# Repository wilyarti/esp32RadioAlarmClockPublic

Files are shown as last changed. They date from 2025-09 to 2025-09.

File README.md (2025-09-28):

# Thanks to:
- https://oleddisplay.squix.ch/ <- font generation
- https://javl.github.io/image2cpp/
- https://www.svgrepo.com/svg/521874/telegram
- Volos Projects for inspiration

I'll help if you need it. Basically in TFT eSPI library set the config for your screen.

In hardware_definitions.h set you i2s pins.

WiFi configuration and Telegram token setting is done via serial on boot.

STL files are included for the case.

The license is BSD 2 Clause. Have fun.

Looks like this:

Example of device screen.
Example of device screen.

# Features:
1. Preferences.h configuration of almost all functions
2. Stores 5 WiFi APs and tries each on boot
3. Stores 8 Radio Stations
4. Can play any radio station URL
5. Can be configured via Serial or via telegram
6. Alarm configured via serial/telgram includes volume
7. Power limiting available to reduce battery consumption
8. Has horizontal graphs for volume, buffer and power use
9. Records ping ms for current station
10. Clock and alarm clock use rainbow coloring for HH, MM and SS
11. Timezone programmable
12. Keeps time up to date automagically
13. Has battery and wifi signal icons
14. Lots of other stuff I forgot

# Bugs:
For some reason it plays fine when I proxy high bitrate music streams through my personal server, but struggles when directly streaming.
Some other random memory leaks.
This device isnt super powerful so graphic updates are gradual. Like individual letters, numbers etc are deleted and redrawn. 

# Design:
Uses a "fat struct" called g_machine for almost everything it runs. I've put the functions into seperate libraries. The crazy thing is how good the sound quality is....
As for the hardware I basically just threw parts together.

# Parts list:
- TTGO T4 v1.1 (old stock I had)
- 2PCS 2" 4Ohm 3W DIY Small Full Range Audio Speaker
- TPA3110 XH-A232 30W+30W 2.0 Channel Digital Stereo Audio Power Amplifier Board DC 8-26V 3A
- MCU-219 INA219 I2C port Zero drift bidirectional current power supply monitoring sensor module
- TPS61088 5V 9V 12V Adjustable Boost Step Up Board Module Switch Power Supply Module 
- 3.7V 2500mAh battery (salvaged from somewhere)
- Interface I2S PCM5102A DAC Decoder GY-PCM5102 I2S Player




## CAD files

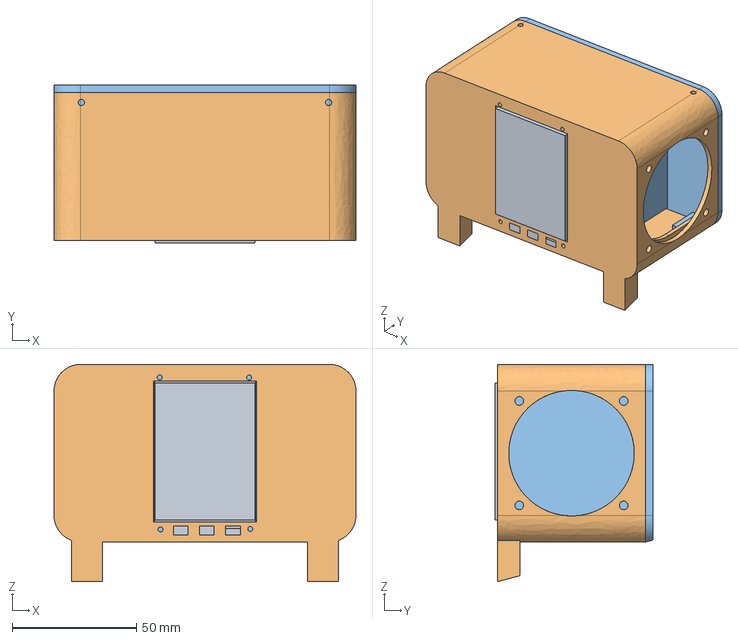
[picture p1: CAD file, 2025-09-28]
3D_models/speaker_box.igs
121.5 x 63.5 x 87.4 mm

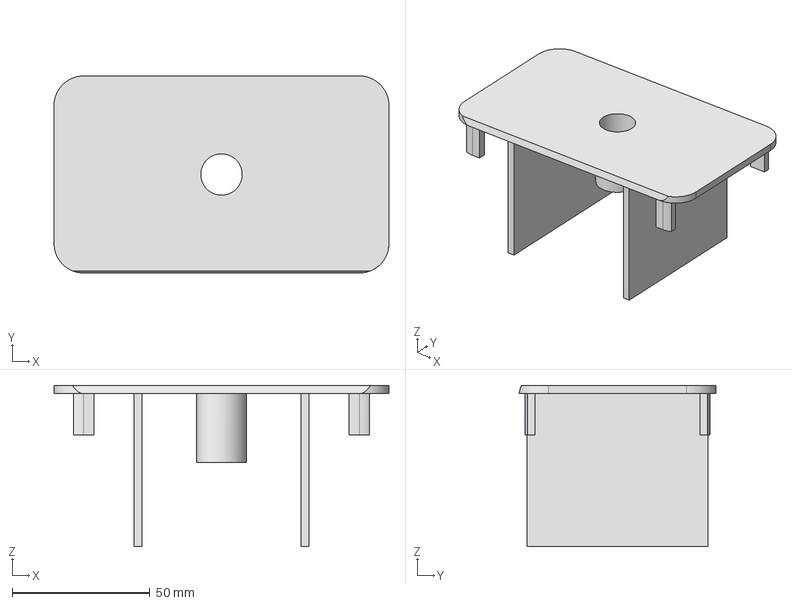
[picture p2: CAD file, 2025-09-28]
3D_models/casing_backing.igs
121.5 x 71.5 x 58.5 mm

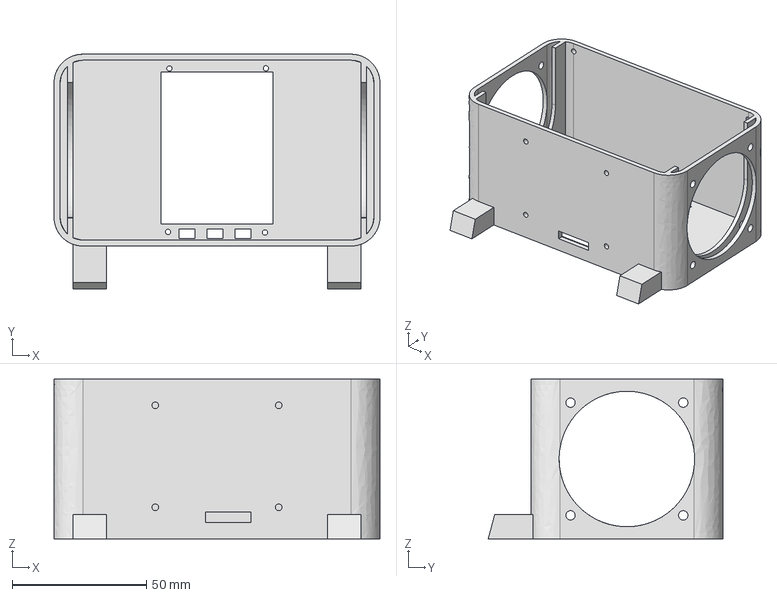
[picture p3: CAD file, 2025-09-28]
3D_models/speaker_box_component.igs
121.5 x 87.4 x 59.5 mm

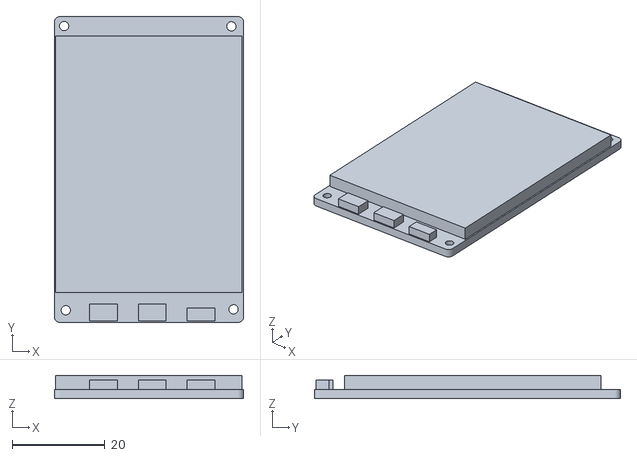
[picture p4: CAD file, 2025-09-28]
3D_models/ttgo_t4.stl
40.8 x 65.9 x 5.00

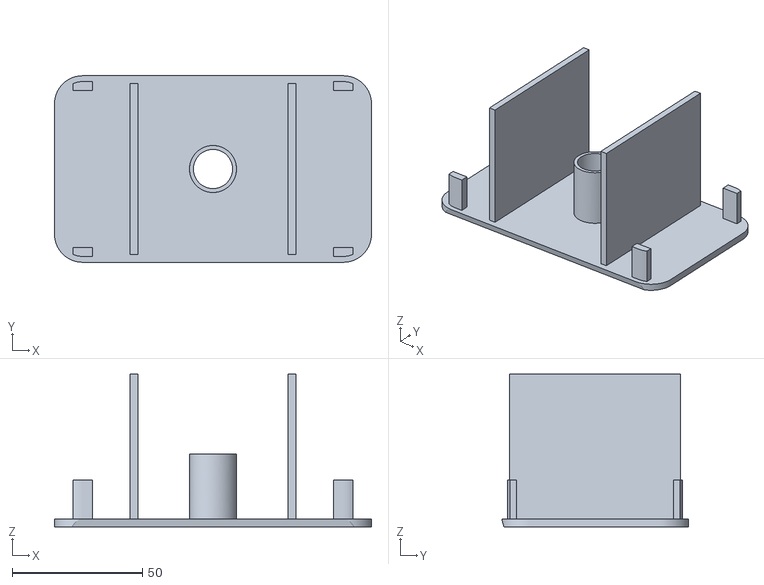
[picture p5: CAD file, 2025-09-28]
3D_models/casing_backing_final.stl
121.5 x 71.5 x 58.5

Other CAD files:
3D_models/speaker_box_component_final.stl
3D_models/speaker_box.stl

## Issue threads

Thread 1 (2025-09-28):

Incorrect 3d STL files....

wilyarti, 2025-09-28:
I gotta upload the right ones.

wilyarti, 2025-09-28:
Fixed

Closed 2025-09-28.

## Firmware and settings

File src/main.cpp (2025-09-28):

#include "main.h"

int sleepTime = 15;
unsigned long curTime;

// ====== Time Keeping =====
long timeZone = 10;
static WiFiUDP ntpUDP;

// ====== Telegram ======
static WiFiClientSecure secureClient;
unsigned long botLastCheck = 0;
const unsigned long botInterval = 2000; // ms

// ======= Hardware Polling and Alarm Check =====
unsigned long lastLoop = 0;
const unsigned long loopControlInterval = 16; // 30 fps
// SPIClass hspi(HSPI);

unsigned long alarmCheck = 0;
const unsigned long alarmCheckInterval = 45000; // 15 secs
unsigned long lastLoopControllerIntervalDecrement = 0;
unsigned long lastLoopControllerIntervalIncrement = 0;

// ====== Buttons ======
const uint8_t BUTTON_PINS[NUM_BUTTONS] = {BUTTON_A, BUTTON_B, BUTTON_C};
Bounce *buttons = new Bounce[NUM_BUTTONS];
bool ramMonitorDuringBoot = false;
bool slowBoot = false;
int LOOP_TARGET = 150;
unsigned long lastPingCheck = 0;

unsigned long screenshotTimer = millis();

void setup() {
    Serial.begin(9600);
    Serial.println("/*** Init Serial ***/");
    if (slowBoot) delay(1000);

    /*** Init TFT ***/
    g_machine.tft = new TFT_eSPI();

    //
    Wire.begin(SDA,SCL);
    g_machine.current_sensor = new INA219(0x40, &Wire); // &Wire is optional
    g_machine.current_sensor->setMaxCurrentShunt(5, 0.1);


    setupDisplay();
    Serial.println("/*** Setup Display ***/");
    if (slowBoot) delay(1000);

    // Load WiFi networks
    loadWiFi();
    // WiFi setup
    if (connectWiFi() == false) {
        setupNetworkViaInput();
    }
    //setupNetworkViaInput(); // Delete this -- testing
    WiFi.setSleep(false);
    WiFi.setTxPower(WIFI_POWER_19_5dBm);
    //WiFi.setRxBufferSize(1024); // ✅ FIXED
    secureClient.setInsecure();
    //secureClient.setCACert(TELEGRAM_CERTIFICATE_ROOT); // Add root certificate for api.telegram.org

    // Initialize state
    loadParamatersOnBoot();
    loadTelegram();
    Serial.println("/*** Loaded Paramaters ***/");
    if (slowBoot) delay(1000);

    setupLayout();
    Serial.println("/*** Setup Layout ***/");
    if (slowBoot) delay(1000);


    g_machine.bot = new UniversalTelegramBot(g_machine.telegramToken, secureClient);
    int numNewMessages = g_machine.bot->getUpdates(g_machine.bot->last_message_received + 1);
    while (numNewMessages) {
        Serial.println("Emptying message queue.");
        numNewMessages = g_machine.bot->getUpdates(g_machine.bot->last_message_received + 1);
    }
    if (slowBoot) delay(1000);

    g_machine.timeClient = new NTPClient(ntpUDP, "pool.ntp.org", g_machine.timeZone * 3600, 60000);
    g_machine.timeClient->begin();
    g_machine.timeClient->setTimeOffset(g_machine.timeZone * 3600L);
    g_machine.timeClient->update();
    Serial.println("/*** TimeZone Setup ***/");

    // Buttons
    for (int i = 0; i < NUM_BUTTONS; i++) {
        buttons[i].attach(BUTTON_PINS[i], INPUT_PULLUP);
        buttons[i].interval(25);
    }
    Serial.println("/*** Button Interups Set ***/");

    // ✅ INITIALIZE AUDIO FIRST!
    Serial.println("Before audio_setup");
    g_machine.audio = new Audio();
    if (!g_machine.audio) {
        Serial.println("❌ Failed to allocate Audio object!");
        while (1);
    }
    audio_setup();
    Serial.println("/*** Audio Setup ***/");

    // ✅ THEN restore radio
    restoreRadioOnBoot();

    // ✅ THEN create tasks with adequate stack
    xTaskCreatePinnedToCore(
        telegramTask, "TelegramTask", 8192, NULL, 1, NULL, 0
    );

    xTaskCreatePinnedToCore(
        timeUpdateTask, "TimeUpdateTask", 2048, NULL, 2, NULL, 0
    );

    Serial.println("/*** Secondary Tasks Launched ***/");

    // hspi.begin(SD_SCK, SD_MISO, SD_MOSI, SD_CS);
    //
    // // Initialize SD card
    // if (!SD.begin(SD_CS, hspi)) {
    //     Serial.println("SD Card Mount Failed");
    //     return;
    // }

    g_machine.loopCount = 0;
    g_machine.loopCheck = millis();
    g_machine.bufferFilled = false;
    g_machine.bufferLowerThreshold = 5; // seconds
    g_machine.bufferLengthsIndex = 0;
    g_machine.bufferIndexCheck = 0;
    for (int i = 0; i < 12; i++) {
        g_machine.bufferLengths[i] = 0;
        g_machine.mWpowerReadings[i] = 0;
    }
    g_machine.mWpowerReadingsIndex = 0;
    g_machine.avgPwrmW = 0;
    g_machine.volumeModifiedTime = millis();

}

float getBufferSlope() {
    float sumX = 0, sumY = 0, sumXY = 0, sumX2 = 0;

    for (int i = 0; i < 12; i++) {
        sumX += i; // x = time index (0 to 11)
        sumY += g_machine.bufferLengths[i]; // y = buffer values
        sumXY += i * g_machine.bufferLengths[i];
        sumX2 += i * i;
    }

    // Slope formula: (n*Σxy - ΣxΣy) / (n*Σx² - (Σx)²)
    return (12 * sumXY - sumX * sumY) / (12 * sumX2 - sumX * sumX);
}

void loop() {
    g_machine.loopCount++; // increment loop counter
    g_machine.audio->loop(); // run audio tasks
    // TODO - is this worth keeping in? I just use it for development.
    // if (millis() - screenshotTimer > 5000) {
    //     Serial.println("Screenshot Timer");
    //     int result = serialScreenServer("screenshot.bmp");
    //     screenshotTimer =millis();
    // }

    // Check alarm periodically
    if (millis() - alarmCheck > alarmCheckInterval) {
        checkAlarm();
        alarmCheck = millis();
    }

    // Update buttons, screen etc
    if (millis() - lastLoop > loopControlInterval) {
        buttonCheck();
        checkSerial();
        displayLoop();
        managePower();
        lastLoop = millis();
    }

    int loopMillis = 250;
    if (g_machine.bufferFilled) {
        loopMillis = 5000; // 5 second sample for the case of bufferfilled
    }
    // Buffer checker array
    if (millis() - g_machine.bufferIndexCheck > loopMillis) {
        g_machine.bufferLengths[g_machine.bufferLengthsIndex] = g_machine.bufferLengthInSeconds;
        g_machine.bufferLengthsIndex += 1;
        if (g_machine.bufferLengthsIndex >= 12) g_machine.bufferLengthsIndex = 0;
        g_machine.bufferIndexCheck = millis();
    }

    int loopMillismW = 80;
    // Power reading sampler
    if (millis() - g_machine.mWpowerReadingsMillis > loopMillis) {
        g_machine.mWpowerReadings[g_machine.mWpowerReadingsIndex] = g_machine.current_sensor->getPower_mW();
        g_machine.mWpowerReadingsIndex += 1;
        if (g_machine.mWpowerReadingsIndex == 12) {
            g_machine.mWpowerReadingsIndex = 0;
        }
        g_machine.mWpowerReadingsMillis = millis();
    }
    // Check every second
    if (millis() - g_machine.loopCheck > 1000) {
        float slope = getBufferSlope();
        /** Two conditional branches.
         * 1. bufferFilled target hasn't been achieved
         * 2. bufferFilled has been achieved and is being depleted or used
         * */
        // Buffer filled once
        if (g_machine.bufferFilled) {
            if (g_machine.bufferLengthInSeconds > 5) {
                vTaskDelay(g_machine.loopRetarder);
                if (slope > 0) {
                    //Serial.printf("Slope was negative: %f.2 \n", slope);
                    g_machine.loopRetarder -= 1;
                } else {
                    //Serial.printf("Slope was positive: %f.2 \n", slope);
                    g_machine.loopRetarder += 1;
                }
            } else {
                g_machine.bufferFilled = false; // reset buffer
            }
        }
        // Buffer not yet filled
        if (!g_machine.bufferFilled) {
            if (g_machine.bufferLengthInSeconds < g_machine.bufferTarget) {
                vTaskDelay(g_machine.loopRetarderShortBuffer);
                if (slope > 0.25) {
                    //Serial.printf("Slope was negative: %f.2 \n", slope);
                    g_machine.loopRetarderShortBuffer -= 1;
                } else {
                    //Serial.printf("Slope was positive: %f.2 \n", slope);
                    g_machine.loopRetarderShortBuffer += 5;
                }
            }
        }


        // Serial.printf("Loop: %uHz, Buffer: %.1ds, Slope: %.2f Play buffer retarder: %d Short buffer retarder: %d \n",
        //               g_machine.loopCount, g_machine.bufferLengthInSeconds, slope, g_machine.loopRetarder, g_machine.loopRetarderShortBuffer);
        g_machine.loopCount = 0;
        g_machine.loopCheck = millis();
    }
}

// Helper function to get current volume (you might need to implement this)
uint8_t getAudioVolume() {
    // Return current volume level from your audio system
    return g_machine.audio->getVolume();
}

void managePower() {
    if (millis() - g_machine.volumeModifiedTime < 2000) {
        return; // only mess with volume every 2 seconds
    }
    if (g_machine.avgPwrmW > g_machine.maxPowerLevelmW) {
        int currentVolume = g_machine.volume;
        currentVolume -= 1;
        setAudioVolume(currentVolume);
        Serial.println("Reduced volume");
        g_machine.volumeModifiedTime = millis();
    }
}

void timeUpdateTask(void *pvParameters) {
    while (true) {
        g_machine.timeClient->update();
        vTaskDelay(30000 / portTICK_PERIOD_MS); // Update time every 30 seconds
    }
}

void telegramTask(void *pvParameters) {
    while (true) {
        try {
            int numNewMessages = g_machine.bot->getUpdates(g_machine.bot->last_message_received + 1);
            while (numNewMessages) {
                Serial.println("got response");
                handleNewMessages(numNewMessages);
                numNewMessages = g_machine.bot->getUpdates(g_machine.bot->last_message_received + 1);
                g_machine.telegramMessageFlag = true;
            }
        } catch (const std::exception &e) {
            Serial.printf("Telegram error: %s\n", e.what());
        }

        if (g_machine.audioIsPlaying && g_machine.currentStream.length() > 0) {
            String url = g_machine.currentStream;
            int hostStart = url.indexOf("://");

            if (hostStart > 0) {
                hostStart += 3; // Move past "://"
                int hostEnd = url.indexOf(':', hostStart);
                if (hostEnd == -1) {
                    hostEnd = url.indexOf('/', hostStart);
                }
                if (hostEnd == -1) {
                    hostEnd = url.length();
                }
                g_machine.host = url.substring(hostStart, hostEnd);

                if (Ping.ping(g_machine.host.c_str(), 5)) {
                    g_machine.newPingFlag = true;
                    g_machine.latestPingTime = Ping.averageTime();
                } else {
                    g_machine.latestPingTime = -1; // Indicates a failed ping
                }
            }
            //Serial.printf("Pinged %s: %dms\n", g_machine.host.c_str(), g_machine.latestPingTime);
        } else {
            g_machine.latestPingTime = 0; // Not playing, so ping is 0/NA
        }
        vTaskDelay(3000 / portTICK_PERIOD_MS); // Check every 2 seconds
    }
}

void buttonCheck() {
    for (int i = 0; i < NUM_BUTTONS; i++) {
        // Update the Bounce instance :
        buttons[i].update();
        if (buttons[i].fell() && i == 0) {
            g_machine.btnState1 = HIGH;
        } else if (buttons[i].fell() && i == 1) {
            g_machine.btnState2 = HIGH;
        } else if (buttons[i].fell() && i == 2) {
            g_machine.btnState3 = HIGH;
        }
    }
}

void checkCpuUsage() {
    Serial.printf("CPU Frequency: %d MHz\n", getCpuFrequencyMhz());
    Serial.printf("CPU Usage: %.1f%%\n", 100.0 - (100.0 * getCpuFrequencyMhz() / 240));
}

void checkFullMemoryStatus() {
    Serial.println("\n--- MEMORY STATUS ---");

    // Internal RAM
    Serial.printf("Internal RAM:\n");
    Serial.printf("  Free: %6d kB\n", ESP.getFreeHeap() / 1024);
    Serial.printf("  Min Free: %6d kB\n", ESP.getMinFreeHeap() / 1024);
    Serial.printf("  Max Alloc: %6d kB\n", ESP.getMaxAllocHeap() / 1024);
    Serial.printf("  Total Size: %6d kB\n", ESP.getHeapSize() / 1024);

    // PSRAM
    if (psramFound()) {
        Serial.printf("PSRAM:\n");
        Serial.printf("  Free: %6d kB\n", ESP.getFreePsram() / 1024);
        Serial.printf("  Min Free: %6d kB\n", ESP.getMinFreePsram() / 1024);
        Serial.printf("  Total Size: %6d kB\n", ESP.getPsramSize() / 1024);
    } else {
        Serial.println("PSRAM: Not detected");
    }

    Serial.printf("Chip Revision: %d\n", ESP.getChipRevision());
    Serial.printf("CPU Frequency: %d MHz\n", ESP.getCpuFreqMHz());
    Serial.println("---------------------");
}

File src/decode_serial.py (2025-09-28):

import serial
import time
from PIL import Image
import argparse


class SerialScreenReceiver:
    def __init__(self, port, baudrate=115200, timeout=10):
        self.ser = serial.Serial(port, baudrate, timeout=timeout)
        self.width = 0
        self.height = 0
        self.pixel_format = "RGB565"

    def wait_for_header(self):
        """Wait for and parse the screenshot header"""
        print("Waiting for SCREENSHOT header...")

        buffer = ""
        while True:
            if self.ser.in_waiting > 0:
                char = self.ser.read(1).decode('ascii', errors='ignore')
                buffer += char

                if "SCREENSHOT:" in buffer:
                    # Send 'S' response immediately
                    print("Sending 'S' response...")
                    self.ser.write(b'S')
                    self.ser.flush()
                    # Extract the parameters line
                    header_start = buffer.find("SCREENSHOT:") + len("SCREENSHOT:")
                    header_end = buffer.find('\n', header_start)
                    if header_end == -1:
                        continue

                    params_line = buffer[header_start:header_end].strip()
                    self.parse_parameters(params_line)
                    return True

    def parse_parameters(self, params_line):
        """Parse screen parameters from header"""
        print(f"Parameters: {params_line}")

        params = {}
        for param in params_line.split(','):
            if '=' in param:
                key, value = param.split('=', 1)
                params[key.strip()] = value.strip()

        self.width = int(params.get('WIDTH', 240))
        self.height = int(params.get('HEIGHT', 320))
        self.pixel_format = params.get('FORMAT', 'RGB565')

        print(f"Screen: {self.width}x{self.height}, Format: {self.pixel_format}")

    def receive_screenshot(self, output_file):
        """Receive the screenshot data and handle the split-screen issue"""
        if not self.wait_for_header():
            print("Failed to receive header")
            return False

        print("Receiving image data...")

        # Determine bytes per pixel
        bytes_per_pixel = 2 if '565' in self.pixel_format else 3

        # Calculate expected data size
        expected_bytes = self.width * self.height * bytes_per_pixel
        received_data = bytearray()
        start_time = time.time()

        try:
            while True:
                if self.ser.in_waiting > 0:
                    chunk = self.ser.read(self.ser.in_waiting)
                    received_data.extend(chunk)

                    # Check for ENDDATA marker
                    if b'ENDDATA' in received_data:
                        end_index = received_data.index(b'ENDDATA')
                        received_data = received_data[:end_index]
                        break

                # Progress update
                if len(received_data) % 1000 == 0:
                    progress = min(100, len(received_data) / expected_bytes * 100)
                    print(f"Received: {len(received_data)}/{expected_bytes} bytes ({progress:.1f}%)")

                # Timeout check
                if time.time() - start_time > 30:
                    print("Timeout!")
                    break

                time.sleep(0.01)

        except KeyboardInterrupt:
            print("Interrupted by user")
            return False

        print(f"Received {len(received_data)} bytes")

        # Fix the split-screen issue by reordering the pixels
        image = self.reconstruct_image(received_data, bytes_per_pixel)
        if image:
            image.save(output_file)
            print(f"Image saved to: {output_file}")
            image.show()
            return True

        return False

    def reconstruct_image(self, data, bytes_per_pixel):
        """Reconstruct the image fixing the split-screen issue"""
        try:
            # Create empty image
            img = Image.new('RGB', (self.width, self.height))
            pixels = []

            if bytes_per_pixel == 2:
                # RGB565 format
                for y in range(self.height):
                    for x in range(self.width):
                        # Calculate the correct index - this fixes the split-screen issue
                        # The issue is likely that pixels are being sent in a different order
                        # than they're being received
                        idx = (y * self.width + x) * 2

                        if idx + 1 < len(data):
                            # Read the pixel data
                            pixel_data = (data[idx] << 8) | data[idx + 1]

                            # Convert RGB565 to RGB888
                            r = ((pixel_data >> 11) & 0x1F) * 255 // 31
                            g = ((pixel_data >> 5) & 0x3F) * 255 // 63
                            b = (pixel_data & 0x1F) * 255 // 31

                            pixels.append((r, g, b))
                        else:
                            pixels.append((0, 0, 0))  # Black for missing pixels
            else:
                # RGB888 format
                for y in range(self.height):
                    for x in range(self.width):
                        idx = (y * self.width + x) * 3

                        if idx + 2 < len(data):
                            r = data[idx]
                            g = data[idx + 1]
                            b = data[idx + 2]
                            pixels.append((r, g, b))
                        else:
                            pixels.append((0, 0, 0))

            # Put the pixels in the image
            img.putdata(pixels)
            return img

        except Exception as e:
            print(f"Error reconstructing image: {e}")
            return None

    def close(self):
        self.ser.close()


def main():
    parser = argparse.ArgumentParser(description='Receive screenshot from serial')
    parser.add_argument('port', help='Serial port (COM3, /dev/ttyUSB0, etc.)')
    parser.add_argument('-o', '--output', default='screenshot.png', help='Output file')
    parser.add_argument('-b', '--baud', type=int, default=115200, help='Baud rate')

    args = parser.parse_args()

    receiver = SerialScreenReceiver(args.port, args.baud)

    try:
        if receiver.receive_screenshot(args.output):
            print("Screenshot received successfully!")
        else:
            print("Failed to receive screenshot")
    except Exception as e:
        print(f"Error: {e}")
    finally:
        receiver.close()


if __name__ == "__main__":
    main()

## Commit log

2025-09-28 Upload correct 3D files and STLs
    Added files as per issue #1
    [casing_backing.igs, casing_backing_final.stl, speaker_box.igs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]
2025-09-28 Delete 3D_models/base.stl
    wrong 3d file
    [base.stl]
2025-09-28 Delete 3D_models/bottom_casing_rev2.stl
    wrong file
    [bottom_casing_rev2.stl]
